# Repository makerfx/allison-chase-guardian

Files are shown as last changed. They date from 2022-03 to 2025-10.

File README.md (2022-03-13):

# Allison Chase's Decayed Guardian Cosplay from Breath of the Wild
This repository holds the code for the interactive bits of Allison Chase's Decayed Guardian Cosplay from Breath of the Wild

Check out Allison's [GOFUNDME for the Guardian Cosplay](https://www.gofundme.com/f/decayed-guardian-cosplay) for more info, follow [Allison on Instagram](https://www.instagram.com/aachase1401) and on [TikTok](https://www.tiktok.com/@allison.chase.cosplay) for build progress!

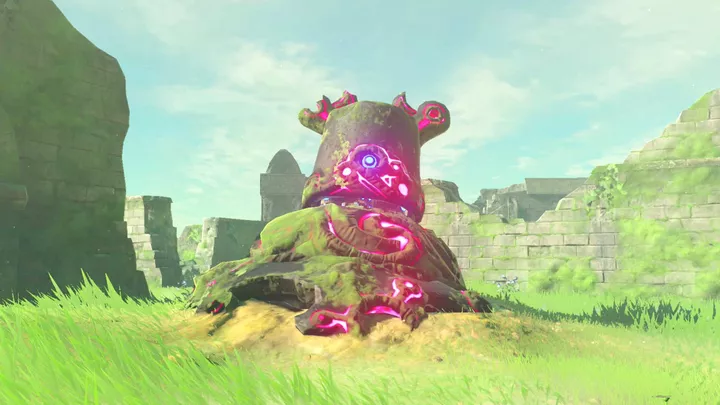
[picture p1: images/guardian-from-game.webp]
Decayed Guardian from Breath of the Wild


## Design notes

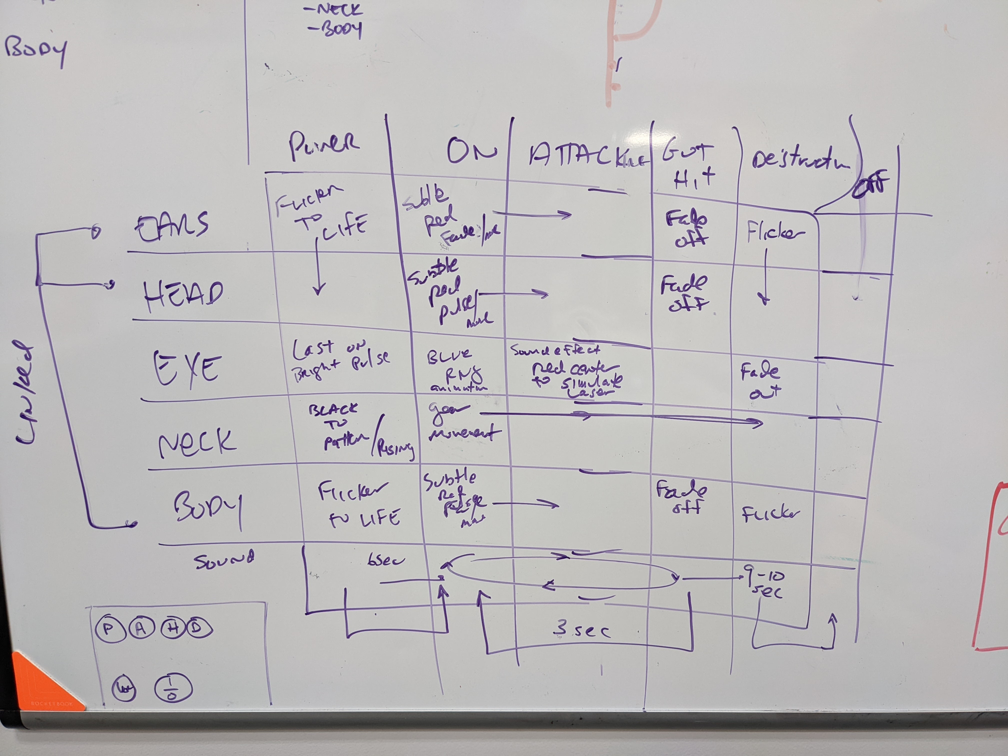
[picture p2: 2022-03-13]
images/modes-whiteboard.jpeg

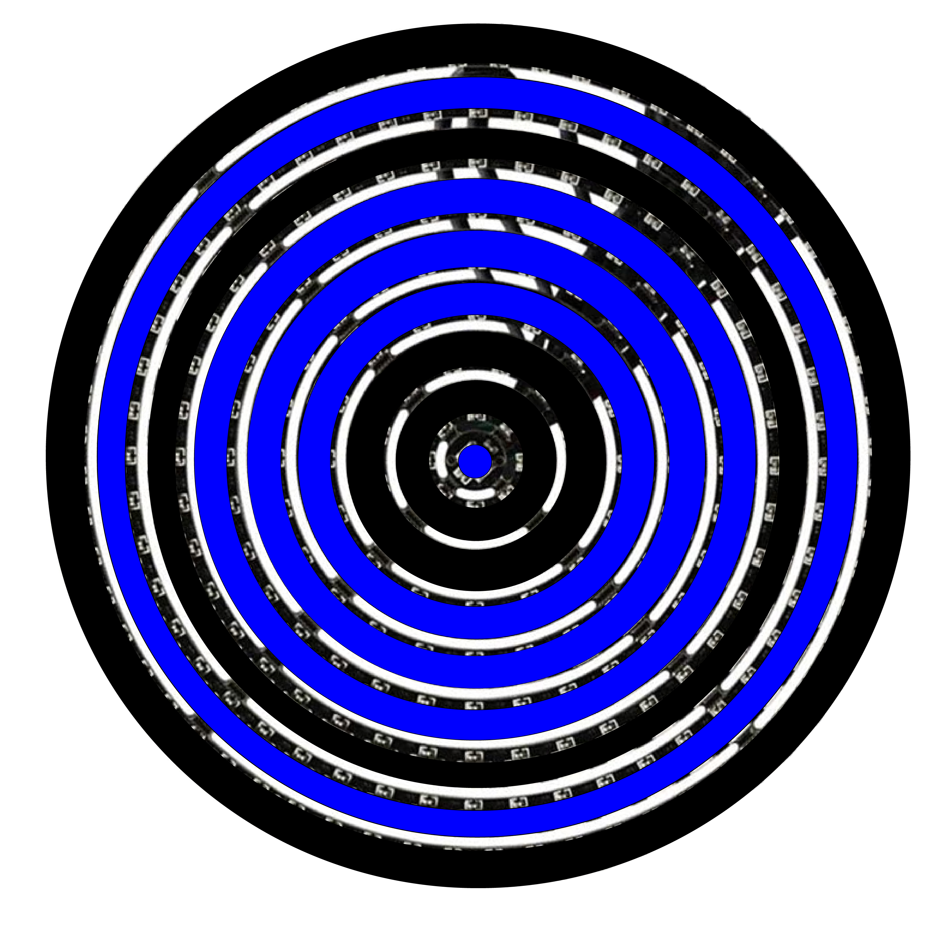
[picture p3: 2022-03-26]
images/pixel-ring-mockups/pixel-ring-mockup-02.png

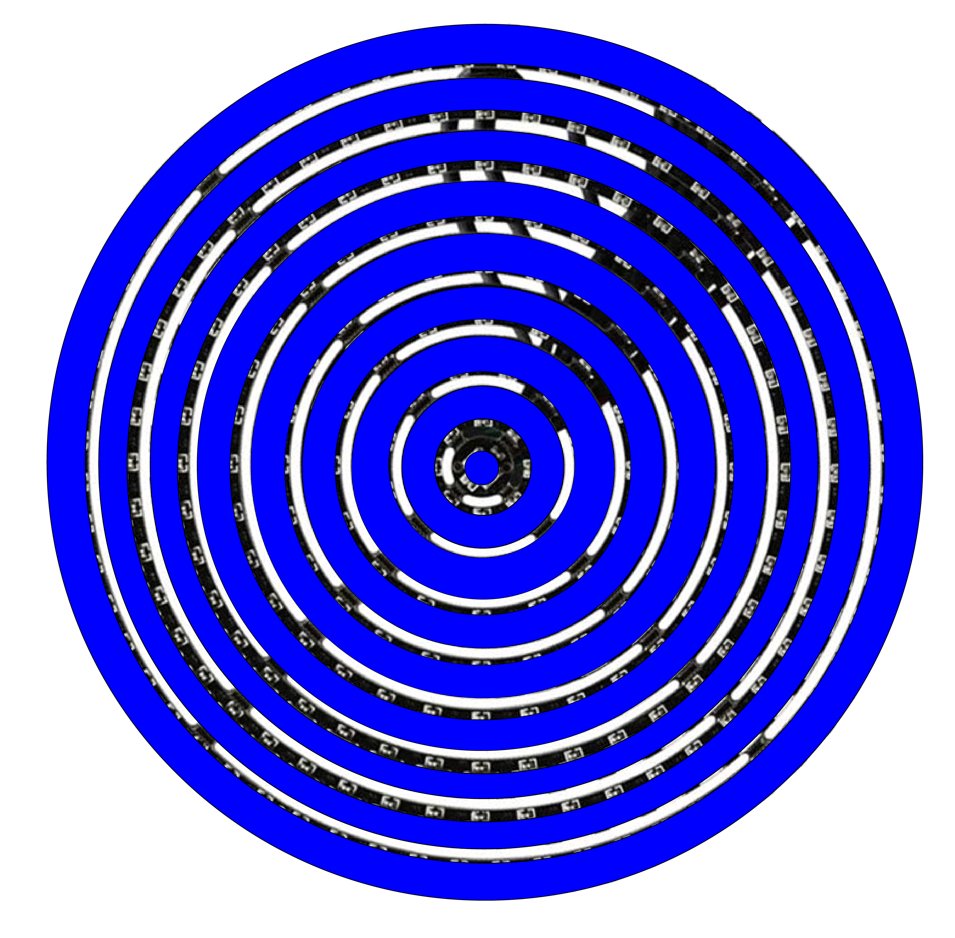
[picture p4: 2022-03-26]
images/pixel-ring-mockups/pixel-ring-mockup-01.png

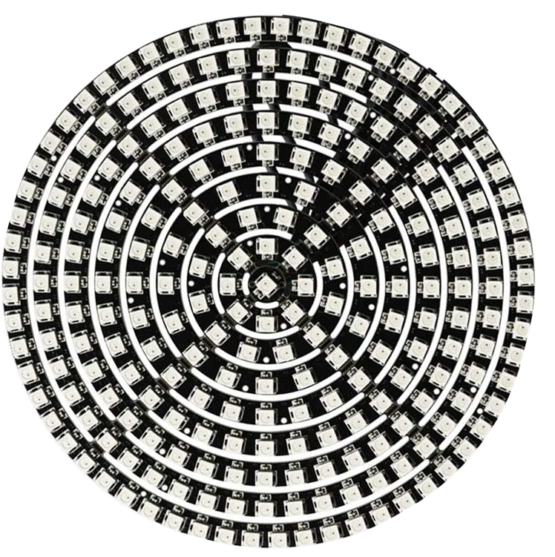
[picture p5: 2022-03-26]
images/pixel-ring.png

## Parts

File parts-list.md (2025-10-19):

# Allison Chase Decayed Guardian Parts List

## Controller & Interface
- Magic Wheelchair "Motherboard" v1.0.7 from MakerFX / 2-Pi Labs
  - 12v -> 5v LM2596 Power Regulator ($1.25) [Amazon Link](https://www.amazon.com/gp/product/B07RLR8PBF)
  - Teensy 4.1 ($26.85): [PJRC link - Buy direct!](https://www.pjrc.com/store/teensy41.html) (also available on amazon)
  - Teensy Audio board REV D for Teensy 4 ($13.75): [PJRC link - Buy direct!](https://www.pjrc.com/store/teensy3_audio.html)
  - Header pins for protoboards ($13 kit): https://smile.amazon.com/gp/product/B07CWSXY7P/
  - 8GB Micro SD Card - SanDisk Industrial with reader ($13.43) [Amazon Link](https://www.amazon.com/gp/product/B085GL8XBH)
  - USB Host Cable for Teensy ($8 for 2): https://www.amazon.com/gp/product/B06Y5M6JTV
  - 5 Key OSU Keyboard ($24.99): [Amazon Link](https://www.amazon.com/gp/product/B08R9GN82G/?th=1)
  - Wireless Presenter Remote ($14.59): [Amazon Link](https://www.amazon.com/gp/product/B01410YNAM/) (STILL NOT INTEGRATED)
  - OLED screen .91 inch ($12.99): [Amazon Link](https://www.amazon.com/gp/product/B07PDFCVXL)

## Power
- Batteries - GigaParts PO4Power 12V 24AH LifePO4 Battery x4 (two on-board, two reserve) ($199.99 each)
- Battery Mount - 3D Printed from DeltaMaker - STL file in Repo
- Battery Straps ($6.99) - [Amazon Link](https://www.amazon.com/gp/product/B078P3GMWV)
- Battery Charger (Loaner from MakerFX - $105.00) - [Amazon Link](https://www.amazon.com/gp/product/B08C2JN76Q)
- Power Supply 12v 600watt Max ($59.99) - [Amazon Link](https://www.amazon.com/gp/product/B082NSVWJY)
- Power Regulation 12v -> 5v @ 20amp x2 ($17.99 each) [Amazon Link](https://smile.amazon.com/gp/product/B089M5R3NJ)
- Fuse Block - 6 circuit with ground bus x2 (18.89 each) [Amazon Link](https://www.amazon.com/gp/product/B08NPMFBBW/)
- XT90 Battery Connectors - 3 pairs - 2x ($13.99 each) [Amazon Link](https://www.amazon.com/gp/product/B08L3RS5HP)
- Main Battery Cable - 10 gauge stranded speaker wire 100 ft ($39.95) [Amazon Link](https://www.amazon.com/gp/product/B00J357DGW)
- Power Distribution Cable - 16 gauge 2 conductor 100 ft. ($18.99) [Amazon Link](https://www.amazon.com/gp/product/B07SG23DT1)

## Cable Management
- Ceiling Cable Management System for VR ($20.79) [Amazon Link](https://www.amazon.com/gp/product/B0777H24ZG)

## LEDs (>3500!)
- Eye + Body Circles: 241 LED Concentric Rings($29) [Amazon Link](https://smile.amazon.com/gp/product/B083VWVP3J)= 177 LEDs (we did not use the outer ring)
- Ears: WS2812 5.5mm Narrow White PCB 2m 120 LEDs ($18.49 each) [Amazon link](https://smile.amazon.com/gp/product/B08SBWCVGX) x6 = 720 LEDs
- Body: WS2812 White PCB 5m 300 LEDs ($33.49 each) [Amazon Link](https://smile.amazon.com/gp/product/B01CDTEH3Q/) x6 = 1800 LEDs
- Neck: WS2812 Black PCB 5m 300 LEDs ($33.49 each) [Amazon Link](https://smile.amazon.com/gp/product/B01CDTEKAG) x3 = 900 LEDs
- Male/Female LED connector ($10.99) [Amazon Link](https://smile.amazon.com/dp/B00NBSH4CA/)
- LED Extension Cable: 3 pin 18 gauge 10m () x2 ($12.49 each) [Amazon Link](https://www.amazon.com/gp/product/B07SKGTCWQ)
- LED Data cable 18 gauge green 100ft ($13.22) [Amazon Link](https://www.amazon.com/gp/product/B00J31QVDC)

## Camera System
- Automotive Dashcam System ($105.00) [Amazon Link](https://www.amazon.com/gp/product/B0824M6YKF)
- Sandisk 128GB MicroSD card ($17.99) [Amazon Link](https://www.amazon.com/gp/product/B08GYKNCCP)

## Audio
 - Amplified Speakers ($99.99) [Best Buy Link](https://www.bestbuy.com/site/boss-audio-systems-mcbc425ba-black-chrome/)
 - PAC Noise Filter ($11.49) [Amazon Link](https://www.amazon.com/gp/product/B01LXGH3KC/ref)
 - Headphone Extension Cable 15 feet [Amazon Link](https://www.amazon.com/gp/product/B091KK5HGG)

## Cooling Fan
 - 12v fan pulled from an old computer power supply at MakerFX

## Other Misc Supplies
- 16mm Thread Male Female Panel Metal Aviation Connector Plug - 2x 4pin & 2x 5pin  ($19.93 for assortment) [Amazon Link](https://www.amazon.com/gp/product/B07F5B5LLX)
- LOTS of crimp on rings from Skycraft Surplus

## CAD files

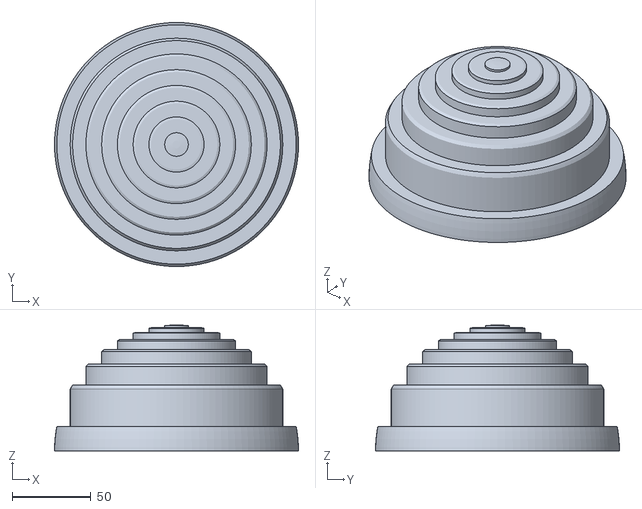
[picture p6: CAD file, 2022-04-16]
3D-printing/led2_2_70mm.stl
154.9 x 154.9 x 80.0

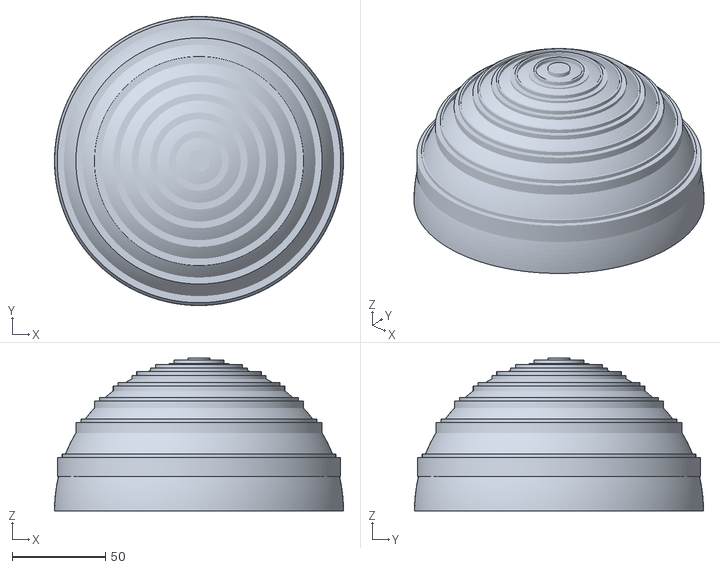
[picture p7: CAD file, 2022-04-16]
3D-printing/ac-guardian-dome-v2-defaults.stl
155.0 x 155.0 x 82.0

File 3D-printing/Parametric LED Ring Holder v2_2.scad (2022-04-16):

/////IGNORE, SETTING VARIABLES/////

/* [Hidden] */
//Resolution 
$fn = 100;
ring1 = 12;
ring2 = 32;
ring3 = 52;
ring4 = 72;
ring5 = 92;
ring6 = 112;
ring7 = 132;
ring8 = 152;
ring9 = 172;

//Width of platform (in mm)
ringBaseWidth = 8.2;

ringBaseHeight = 1;

///////////////////////////////////////////////////////////////





/////EDIT INFO BELOW FOR CUSTOMIZATION/////
/* [Parameters] */
//Overall height of model (in mm)
domeHeight = 80;
//Overall width of model (in mm)
domeWidth = 155;
//Thickness of dome shell (in mm)
domeThickness = 10;

includeRing1 = true;
includeRing2 = true;
includeRing3 = true;
includeRing4 = true;
includeRing5 = true;
includeRing6 = true;
includeRing7 = true;
includeRing8 = true;
includeRing9 = false;





/////////////////////////////////////////////////////////////
////Setup////

// Creating ringsActive vector
ringsAvailable = [ring1, ring2, ring3, ring4, ring5, ring6, ring7, ring8, ring9];

includes = [includeRing1, includeRing2, includeRing3, includeRing4, includeRing5, includeRing6, includeRing7, includeRing8, includeRing9];

ringsActive = [
    for(i = [0:len(ringsAvailable) - 1])
    if(includes[i])
    ringsAvailable[i]
];
    
ringNumber = len(ringsActive);

assert(ringsActive[ringNumber-1]<=domeWidth, "One or more of the rings selected will not fit within the dome");
    

difference(){
union(){
    difference(){
color("red")
    scale([1, 1, (domeHeight*2)/domeWidth]) sphere(d = domeWidth);
    for(i=[0:ringNumber-1])
{
  translate([0,0,(domeHeight*sqrt(pow((domeWidth/2),2)-pow((ringsActive[i]/2),2))/(domeWidth/2))])
    scale([1,1,domeHeight]) difference(){
      cylinder(h=ringBaseHeight, d=ringsActive[i], center=false);
      cylinder(h=ringBaseHeight+2, d=ringsActive[i]-((ringBaseWidth*2)+.6), center=false);
    }
}
  }
    
color("cyan")
  if (ringsActive[0] == ring1)
  {
    union(){
    translate([0,0,(domeHeight*sqrt(pow((domeWidth/2),2)-pow((6),2))/(domeWidth/2))]) cylinder(h=.1, d=14.5, center=false);
    difference(){
        translate([0,0,(domeHeight*sqrt(pow((domeWidth/2),2)-pow((6),2))/(domeWidth/2))]) cylinder (h=2, d=14.5, center=false);
        translate([0,0,(domeHeight*sqrt(pow((domeWidth/2),2)-pow((6),2))/(domeWidth/2))]) cylinder (h=2.2, d=12.5, center=false);
          }
      }
  }
}
color("red")
scale([1, 1, (domeHeight*2)/domeWidth]) sphere(d = domeWidth-(domeThickness*2));
translate([0,0,-domeHeight]) cube([domeWidth,domeWidth,domeHeight*2],center = true);
}

        

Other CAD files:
3D-printing/Parametric LED Ring Holder v2.scad
3D-printing/Parametric LED Ring Holder v2_1.scad

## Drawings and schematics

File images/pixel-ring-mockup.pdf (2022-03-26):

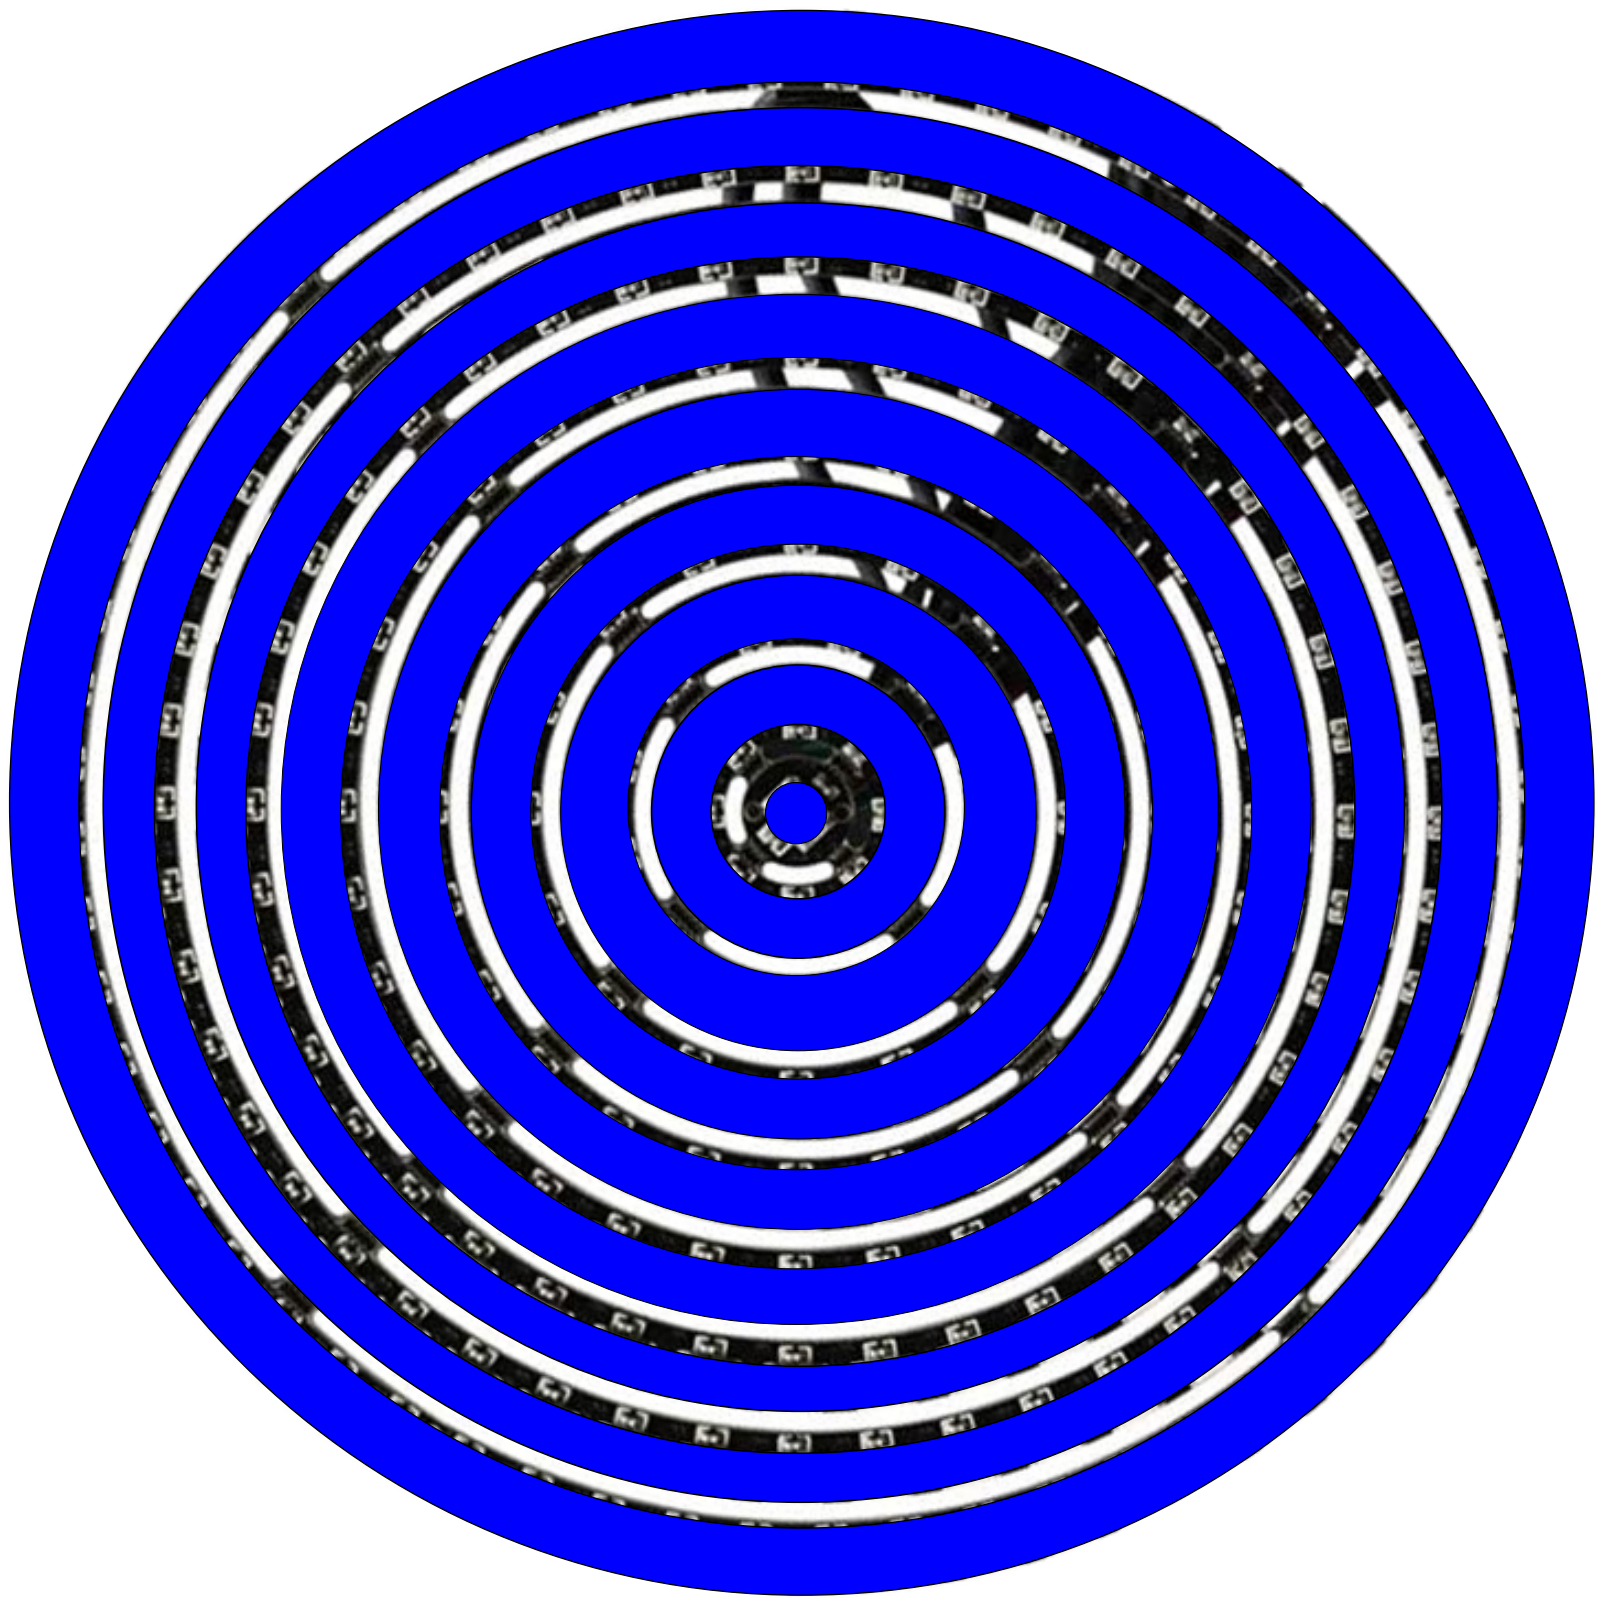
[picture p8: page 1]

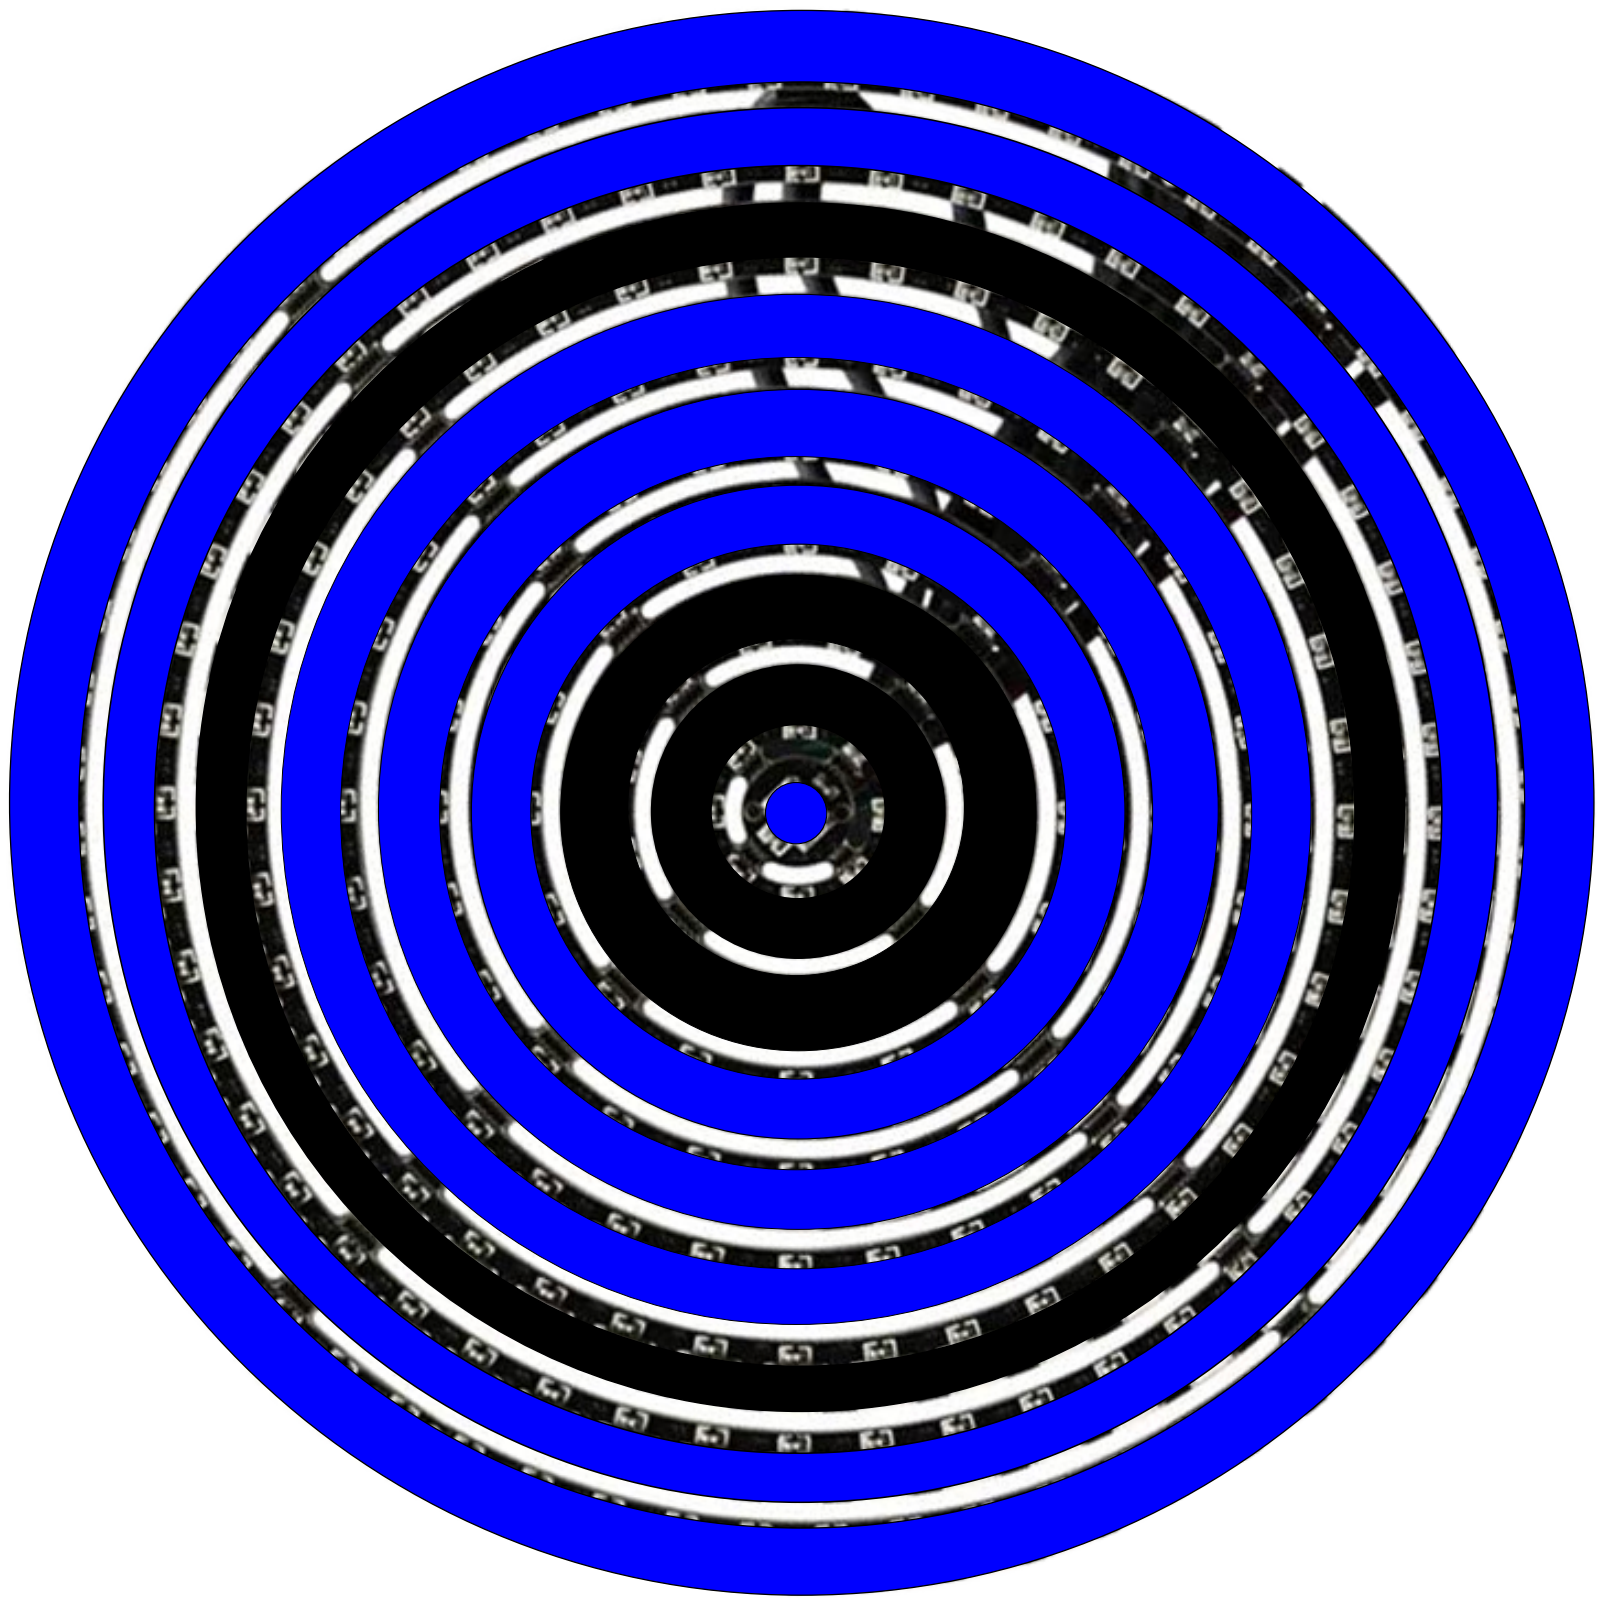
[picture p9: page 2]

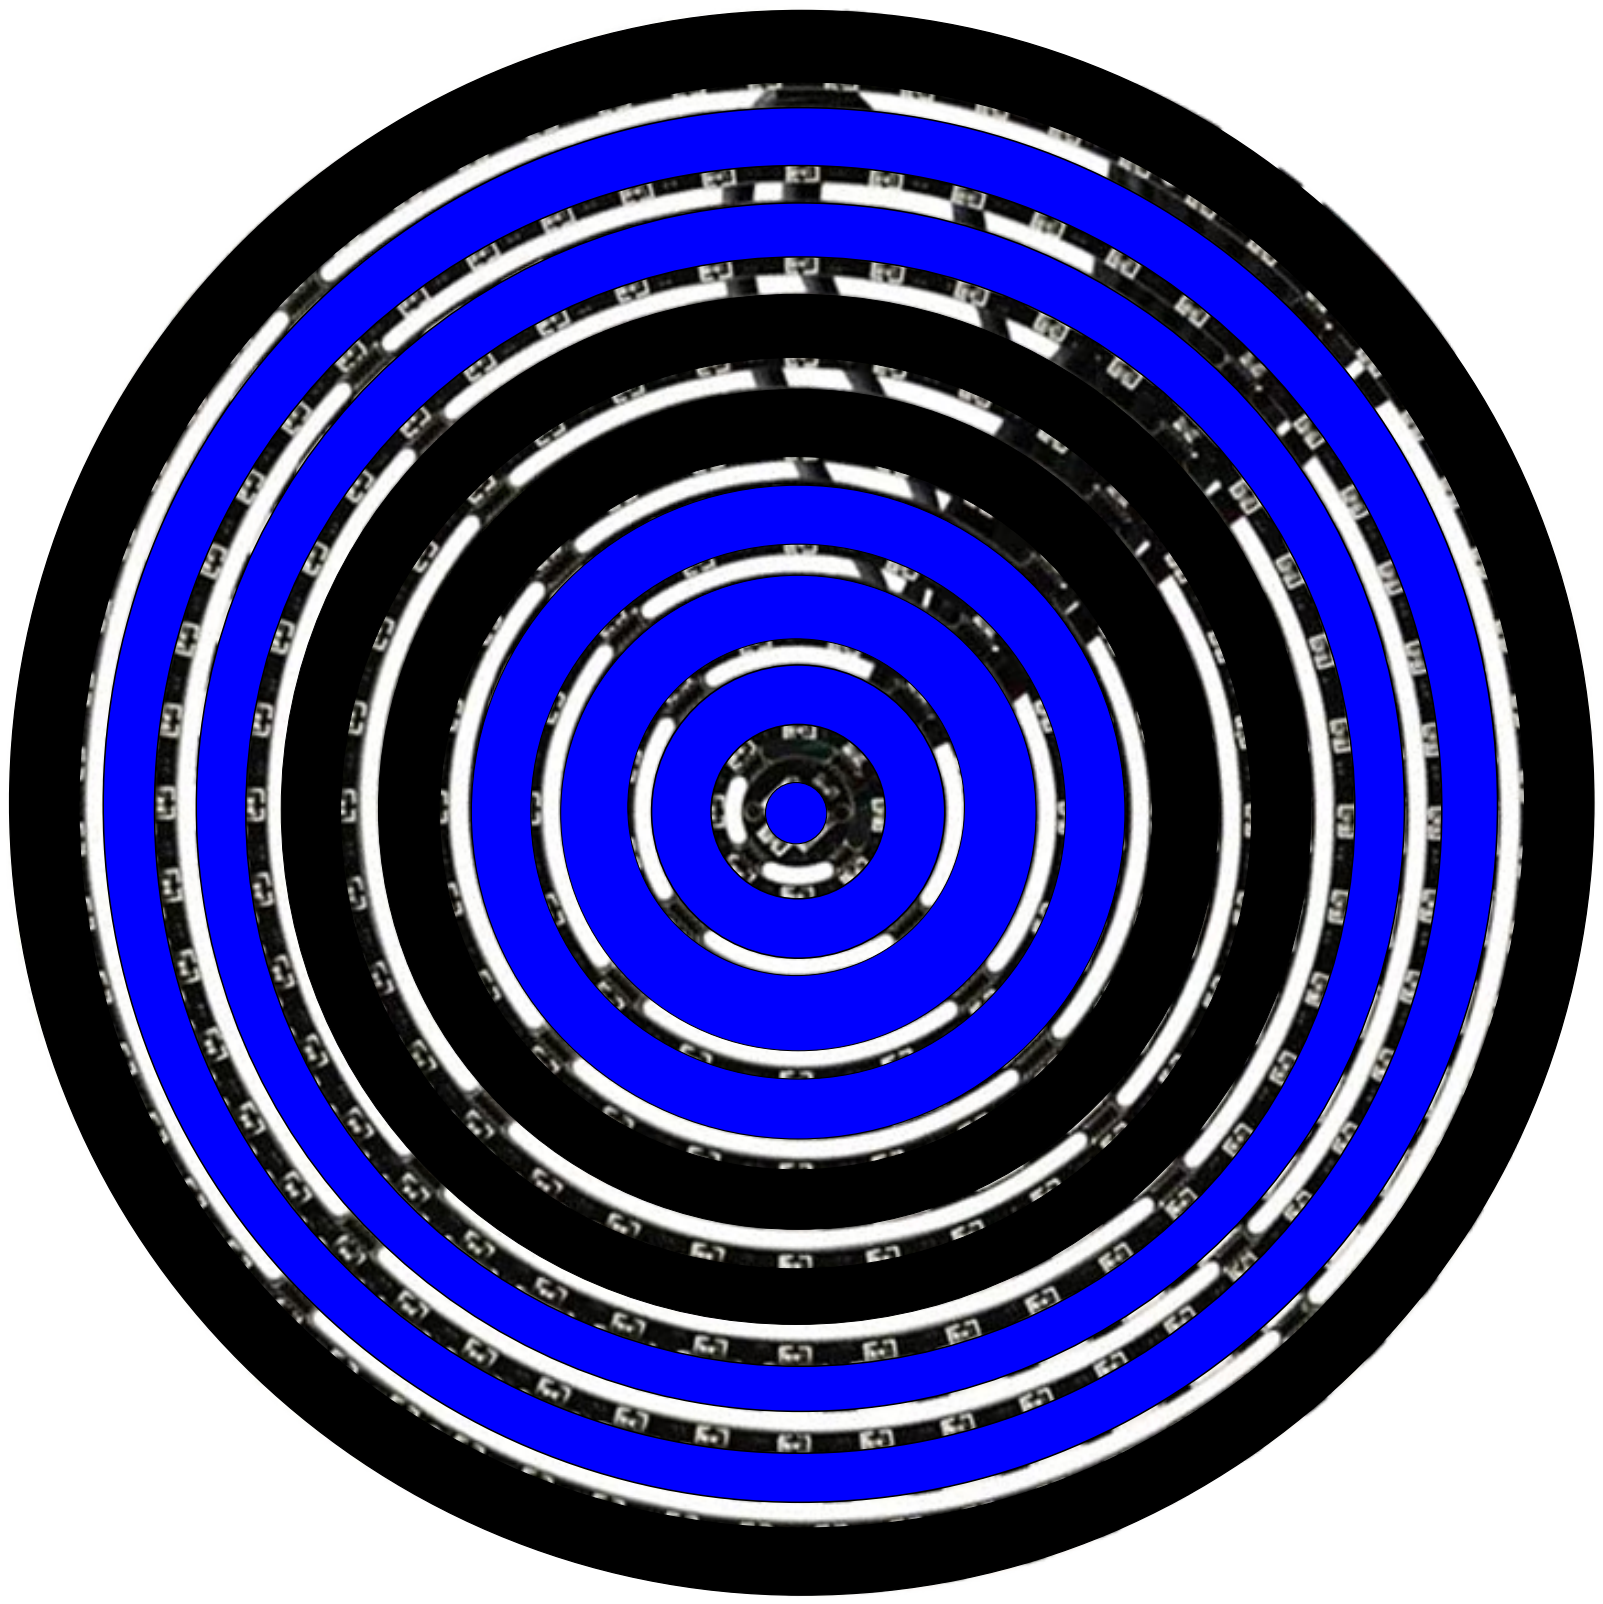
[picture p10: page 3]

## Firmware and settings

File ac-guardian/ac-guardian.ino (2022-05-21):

#include "ac-guardian.h"

void setup() {
  // put your setup code here, to run once:
  randomSeed(analogRead(0));
  Serial.begin(115200);
  delay(200);

  //usb setup
  //don't forget to add these for EVERY keyboard :)
  
  osukey1.attachRawPress(OnPress);
  osukey1.attachRawRelease(OnRelease);
  osukey2.attachRawPress(OnPress);
  osukey2.attachRawRelease(OnRelease);
  osukey3.attachRawRelease(OnRelease);
  osukey3.attachRawPress(OnPress);
  osukey4.attachRawRelease(OnRelease);
  osukey4.attachRawPress(OnPress);
  osukey5.attachRawRelease(OnRelease);
  osukey5.attachRawPress(OnPress);
  myusb.begin();
  
  //display init
  // SSD1306_SWITCHCAPVCC = generate display voltage from 3.3V internally
  if(!display.begin(SSD1306_SWITCHCAPVCC, 0x3C)) { // Address 0x3C for 128x32
    Serial.println(F("SSD1306 allocation failed"));
    for(;;); // Don't proceed, loop forever
  }
  Serial.println("OLED begun");
  
  // Clear the buffer
  display.clearDisplay();

  // text display tests
  display.setTextSize(1);
  display.setTextColor(SSD1306_WHITE);
  display.setCursor(0,0);
  display.println(__FILENAME__);
  display.print(__DATE__);
  display.print(" ");
  display.println(__TIME__);
  display.println("Initializing...");
  display.display(); // actually display all of the above

  Serial.println("Setup Started.");

    //setup audio system
  AudioMemory(128);
  sgtl5000_1.enable();
  sgtl5000_1.volume(mainVolume);

  //set relative volumes by channel
  mixer1.gain(0, LEVEL_CHANNEL0);
  mixer2.gain(0, LEVEL_CHANNEL0);
  mixer1.gain(1, LEVEL_CHANNEL1);
  mixer2.gain(1, LEVEL_CHANNEL1);
  mixer1.gain(2, LEVEL_CHANNEL2);
  mixer2.gain(2, LEVEL_CHANNEL2);

  //setup SD card
  SPI.setMOSI(SDCARD_MOSI_PIN);
  SPI.setSCK(SDCARD_SCK_PIN);
  if (!(SD.begin(SDCARD_CS_PIN))) {
    while (1) {
      Serial.println("Unable to access the SD card");
      delay(500);
    }
  }
  
  LEDS.addLeds<WS2812SERIAL,  NECK_DATA_PIN,   BRG>(neckLEDs,  NUM_NECK_LEDS);
  LEDS.addLeds<WS2812SERIAL,  EYE_DATA_PIN,    BRG>(eyeLEDs,   NUM_EYE_LEDS);
  LEDS.addLeds<WS2812SERIAL,  BODY_DATA_PIN,   BRG>(bodyLEDs,  NUM_BODY_LEDS);
  
    
  //LEDS.setBrightness(DEFAULT_BRIGHTNESS);
  updateBrightness(); //will set the default
  
  //build the top ring pattern to be copied later
  for (int i=0; i<NECK_TOP_GEARS_NUM; i++) { 
     for (int j=0; j<NECK_TOP_GEAR_WIDTH; j++) {
        if (j==0 || j==3) neckTopPattern[i*NECK_TOP_GEAR_WIDTH + j] = 1;
        else neckTopPattern[i*NECK_TOP_GEAR_WIDTH + j] = 0;
      }
  }

  if (debugOptions[DEBUG_ANIMATION_NECK]) {
    //print the ring pattern
    for (int i=0; i<NUM_NECK_LEDS_PER_RING ; i++) { 
       Serial.print(neckTopPattern[i]);
    }   
    Serial.println("");  
  }

  //build the body pattern
  generateBodyPattern();


  delay (2000);
  display.clearDisplay();
  display.setCursor(0,0);
  display.println("Running...");
  display.setCursor(0,0);
  display.display(); // actually display all of the above
  printDebugOptions();

/*
  Serial.println(bodySpotColor.red);
  Serial.println(bodySpotColor.green);
  Serial.println(bodySpotColor.blue);

  Serial.println("");
  Serial.println(bodySpotGapColor.red);
  Serial.println(bodySpotGapColor.green);
  Serial.println(bodySpotGapColor.blue);
 */
  
  //modePowerUp();
}

void loop() {

  EVERY_N_MILLISECONDS(10) {                           
    FastLED.show();
    gHue++; 
  }
  
  EVERY_N_MILLISECONDS(100) {                           
    updateOLED();
    //FastLED.show();
    debugOptionsCheck();
  }
   
   if (queueMetro.check() == 1) { //time to process the queues

    for (int q = 0; q < NUM_ACTIONS; q++) {
      unsigned long qTime = actionQueue[q];
      if (qTime && (millis() > qTime)) {
        if (debugOptions[DEBUG_ACTION]) Serial.printf ("Action Called: %s \n", actionsText[q]);
        if (q==ACTION_FADE_OUT_EYE) eyeAniMode = 0;
        else if (q==ACTION_FADE_IN_EYE) eyeAniMode = 1;       
        else if (q==ACTION_FADE_OUT_NECK) neckAniMode = 0;
        else if (q==ACTION_FADE_IN_NECK) neckAniMode = 1;
        else if (q==ACTION_FADE_OUT_BODY) bodyAniMode = 0;
        else if (q==ACTION_FADE_IN_BODY) bodyAniMode = 1;
        else if (q==ACTION_PLAY_LASER_SOUND) playWAV(CHANNEL_SFX1, "ACGLAZR1.WAV"); //todo: something with the body lights?
        
        else if (q==ACTION_SET_MODE_OFF) mode = MODE_OFF;
        else if (q==ACTION_SET_MODE_IDLE) mode = MODE_IDLE;
        
        actionQueue[q]=0;
      }
    }
    
  

    bool block = false;
    //play any queued music
    for (int q = 0; q < NUM_CHANNELS; q++) {
      String fn = playQueue[q];
      if (fn.length() >0) {
        playQueue[q] = "";
        playWAV(q,fn); 
        block = true;
      }
    }

    //loop BGM if needed - todo: have global for filename to loop
    if ( !block && (musicLoop==true) && !(channels[CHANNEL_MUSIC]->isPlaying())) {
      if(debugOptions[DEBUG_AUDIO]) Serial.println("Audio: restarting music loop");
      //playWAV(CHANNEL_MUSIC, "ACGBATL2.WAV");
      playWAV(CHANNEL_MUSIC, musicLoopFilename);
      if (mode == MODE_POWER_UP) mode = MODE_IDLE;
    }
  } //end playQueueMetro check
  
  if (brMetro.check() == 1) { // check if the bottom ring metro has passed its interval 
    if (neckAniMode == 0) fadeToBlackBy(neckLEDs+NUM_NECK_LEDS_PER_RING, NUM_NECK_LEDS_PER_RING*(NUM_NECK_RINGS-1), 60);
    else if (neckAniMode == 1) updateNeckBottomRings();
    
  }

  if (trMetro.check() == 1) { // check if the top ring metro has passed its interval 
     if (neckAniMode == 0) fadeToBlackBy(neckLEDs, NUM_NECK_LEDS_PER_RING, 60); //just the top ring
     else if (neckAniMode == 1) updateNeckTopRing();
   
 
  } //end trMetro 
   
  if (eyeMetro.check() == 1) { // check if the eye metro has passed its interval 
  
   if (eyeAniMode == 0) fadeToBlackBy(eyeLEDs, NUM_EYE_LEDS, 60);
   else if (eyeAniMode == 1) updateEyeRingStatus();
   else if (eyeAniMode == 2) updateEyeTargeting();
   
  }  //end eyeMetro 
  
  if (bodyMetro.check() == 1) updateBodyLEDs();
  
}

/*
 * generateBodyPattern() - this function generates a random pattern that is then animated
 *                        by updateBodyLEDs()
 *                        
 */
void generateBodyPattern() {
  bool pType = 1;
  CRGB pVal;
  uint8_t pLen;
  
  for (uint16_t l=0; l<NUM_BODY_LEDS; l++) {
    if (pType) {
      pLen = random(BODY_SPOT_LEN_MIN, BODY_SPOT_LEN_MAX);
      //pVal = BODY_SPOT_V;
      //pVal = BODY_SPOT_COLOR;
      pVal = bodySpotColor;

      }
    else {
      pLen = random(BODY_SPOT_GAP_LEN_MIN, BODY_SPOT_GAP_LEN_MAX);
      //pVal = BODY_BASE_V;
      //pVal = BODY_SPOT_GAP_COLOR;
      pVal = bodySpotGapColor;
    }

    for (uint8_t pLED = 0; pLED<pLen; pLED++) {
      //Serial.print(l+pLED);
      
      if (l+pLED>=NUM_BODY_LEDS) break;
      bodyPattern[l+pLED] = pVal;
 
      /*
       if (pVal == bodySpotColor) {
        Serial.print("#");
      }
      else if (pVal == bodySpotGapColor) Serial.print(".");
      */
    }
 
    l = l + pLen - 1;
    if (l>=NUM_BODY_LEDS) break;
    pType = !pType;
  }
}

void updateBodyLEDs() {
  if (bodyAniMode == 0) {
    fadeToBlackBy(bodyLEDs, NUM_BODY_LEDS, 60);
    return;
  }
  else if (bodyAniMode == 1) {//normal body operation

    if (bodyOffset == bodyTarget) {
          bodyDir = !bodyDir;
          bodyTarget = random(0, NUM_BODY_LEDS);
          if (random(1,20) >= BODY_SPEED_RANDOM_CHECK_TURN) {
              bodySpeed = random(BODY_SPEED_MIN,BODY_SPEED_MAX);
          }
          bodyMetro.interval(bodySpeed);
          //Serial.print("reverse - new target = "); Serial.println(bodyTarget);
        }
      
        //decel math
        int dist = abs(bodyOffset-bodyTarget);
        
        if (dist < BODY_DECEL_DISTANCE) {
          int temp_bodySpeed = bodySpeed * (BODY_DECEL_FACTOR/dist);
          if (temp_bodySpeed > BODY_SPEED_MAX_DECEL) {
            temp_bodySpeed = BODY_SPEED_MAX_DECEL;
            bodyMetro.interval(temp_bodySpeed);
          }
          else {
            //random speed changes
            if (random(1,20) >= BODY_SPEED_RANDOM_CHECK) {
              bodySpeed = random(BODY_SPEED_MIN,BODY_SPEED_MAX);
            }
            bodyMetro.interval(bodySpeed);
          }
        }
        
        if (bodyDir) bodyOffset++;
        else bodyOffset --;
      
        
       
        if (bodyOffset >= NUM_BODY_LEDS ) bodyOffset = 0;
        if (bodyOffset < 0) bodyOffset = NUM_BODY_LEDS-1;
        
        //Serial.println(""); Serial.print(bodyOffset); Serial.print("->");
        
        //copy the pattern onto the LED array starting from the top ring offset
        for (int i=0; i<NUM_BODY_LEDS ; i++) { 
           int lo = NUM_BODY_LEDS - bodyOffset + i;
           if (lo > NUM_BODY_LEDS - 1) lo= lo-NUM_BODY_LEDS ;
            bodyLEDs[i] = bodyPattern[lo];
        }  

    }
    else if (bodyAniMode == 2) {//rainbow!!
      //rainbowHue=rainbowHue+10;
      fill_rainbow( bodyLEDs, NUM_BODY_LEDS, gHue, 7);
    }
/*
  //copy the pattern to the LEDs
  for (uint16_t l=0; l<NUM_BODY_LEDS; l++) {
    bodyLEDs[l] = CRGB::Red; 
    bodyLEDs[l] = CHSV(BODY_HUE, 255, bodyPattern[l]);
  }
 */  
 
}
void updateNeckTopRing() {
  
    if (topRingOffset == topRingTarget) {
      topRingDir = !topRingDir;
      topRingTarget = random(0, NUM_NECK_LEDS_PER_RING);
      if (random(1,20) >= TOP_RING_SPEED_RANDOM_CHECK_TURN) {
          topRingSpeed = random(TOP_RING_SPEED_MIN,TOP_RING_SPEED_MAX);
      }
      trMetro.interval(topRingSpeed);
      //Serial.print("reverse - new target = "); Serial.println(topRingTarget);
    }
  
    //decel math
    int dist = abs(topRingOffset-topRingTarget);
    
    if (dist < TOP_RING_DECEL_DISTANCE) {
      int temp_topRingSpeed = topRingSpeed * (TOP_RING_DECEL_FACTOR/dist);
      if (temp_topRingSpeed > TOP_RING_SPEED_MAX_DECEL) {
        temp_topRingSpeed = TOP_RING_SPEED_MAX_DECEL;
        trMetro.interval(temp_topRingSpeed);
      }
      else {
        //random speed changes
        if (random(1,20) >= TOP_RING_SPEED_RANDOM_CHECK) {
          topRingSpeed = random(TOP_RING_SPEED_MIN,TOP_RING_SPEED_MAX);
        }
        trMetro.interval(topRingSpeed);
      }
    }
    
    if (topRingDir) topRingOffset++;
    else topRingOffset --;
  
    
   
    if (topRingOffset >= NUM_NECK_LEDS_PER_RING ) topRingOffset = 0;
    if (topRingOffset < 0) topRingOffset = NUM_NECK_LEDS_PER_RING-1;
    
    //Serial.println(""); Serial.print(topRingOffset); Serial.print("->");
    
    //copy the pattern onto the LED array starting from the top ring offset
    for (int i=0; i<NUM_NECK_LEDS_PER_RING-1 ; i++) { 
       int lo = NUM_NECK_LEDS_PER_RING - topRingOffset + i;
       if (lo > NUM_NECK_LEDS_PER_RING - 1) lo= lo-NUM_NECK_LEDS_PER_RING ;
       if (neckTopPattern[lo]) neckLEDs[i] = CRGB::Blue; 
       else neckLEDs[i] = CRGB::Black;
    }
    //copy the pattern onto the second row of LEDs in reverse (because I had to make things complicated!)
    for (int i=0; i<NUM_NECK_LEDS_PER_RING-1 ; i++) { 
       neckLEDs[i+NUM_NECK_LEDS_PER_RING] = neckLEDs[NUM_NECK_LEDS_PER_RING-i-1];
    }  

    
}
void updateNeckBottomRings() {
  if (bottomRingOffset == 0) bottomRingTargetCycles--;
    if (bottomRingTargetCycles < 0) bottomRingTargetCycles = 0;
  
    if ((bottomRingOffset == bottomRingTarget) && (bottomRingTargetCycles ==0)) {
      bottomRingDir = !bottomRingDir;
      bottomRingTarget = random(0, BOTTOM_RING_GEAR_SIZE);
      bottomRingTargetCycles = random(0, BOTTOM_RING_MAX_CYCLES);
      
      if (random(1,20) >= BOTTOM_RING_SPEED_RANDOM_CHECK_TURN) {
          bottomRingSpeed = random(BOTTOM_RING_SPEED_MIN,BOTTOM_RING_SPEED_MAX);
      }
      brMetro.interval(bottomRingSpeed);
      //Serial.print("reverse - new target = "); Serial.println(bottomRingTarget);
    }
  
    //decel math
    int dist = abs(bottomRingOffset-bottomRingTarget);
    
    if (dist < BOTTOM_RING_DECEL_DISTANCE) {
      int temp_bottomRingSpeed = bottomRingSpeed * (BOTTOM_RING_DECEL_FACTOR/dist);
      if (temp_bottomRingSpeed > BOTTOM_RING_SPEED_MAX_DECEL) {
        temp_bottomRingSpeed = BOTTOM_RING_SPEED_MAX_DECEL;
        brMetro.interval(temp_bottomRingSpeed);
      }
      else {
        //random speed changes
        if (random(1,20) >= BOTTOM_RING_SPEED_RANDOM_CHECK) {
          bottomRingSpeed = random(BOTTOM_RING_SPEED_MIN,BOTTOM_RING_SPEED_MAX);
        }
        brMetro.interval(bottomRingSpeed);
      }
    }
    
    if (bottomRingDir) bottomRingOffset++;
    else bottomRingOffset --;
  
    if (bottomRingOffset >= BOTTOM_RING_GEAR_SIZE ) bottomRingOffset = 0;
    if (bottomRingOffset < 0) bottomRingOffset = BOTTOM_RING_GEAR_SIZE-1;
    
    /*if (debugOptions[DEBUG_ANIMATION_NECK]) {
      Serial.println(""); //Serial.print(bottomRingOffset);Serial.println("->");
    }
  */
    bool tempLEDs[NUM_NECK_RINGS][NUM_NECK_LEDS_PER_RING];

    //init the array with zeros.... NEEDED?
    for (int r = 0; r<NUM_NECK_RINGS; r++) {
      for (int l = 0; l<NUM_NECK_LEDS_PER_RING; l++) {
        tempLEDs[r][l]=0; //clear 
      }
    }
   
    
    for (int r = 0; r<NUM_NECK_RINGS-1; r++) {                                                          //for each ring
      int curLED = 0;
      for (int g = 0; g<(NUM_NECK_LEDS_PER_RING / BOTTOM_RING_GEAR_SIZE)+1 ; g++) {                // for each gear //+1 is hack to fit

        if (g%2==0) { //even number
                                                                    
            for (int l=0; l<BOTTOM_RING_GEAR_SIZE; l++) {
              int lo =  BOTTOM_RING_GEAR_SIZE - bottomRingOffset + l;
              if (lo > BOTTOM_RING_GEAR_SIZE -1) lo= lo- BOTTOM_RING_GEAR_SIZE;
              //Serial.print(lo);Serial.print(" ");
              tempLEDs[r][curLED] = neckFacet[r][lo];         //map facet pattern 
              curLED++;  
            } //end for l
            //Serial.println("");

            
       
       }
       else { //odd number
           int gearEnd = curLED - 1 ; //last LED of prior gear       
   
           for (int l=0; l<BOTTOM_RING_GEAR_SIZE; l++) {                                         
            tempLEDs[r][curLED] = tempLEDs[r][gearEnd - l];
            curLED++;
            } //end for l
        }

        
        //Serial.print(" ");
        } //end for l
    } //end for r 

   /*
  // crazy debug print version
    if (debugOptions[DEBUG_ANIMATION_NECK]) {
      for (int r = 0; r<NUM_NECK_RINGS-2; r++) { //for each ring
  
        Serial.print(r); Serial.print(": ");
        for (int l = 0; l<NUM_NECK_LEDS_PER_RING; l++) {
          if (tempLEDs[r][l] == 1) Serial.print("#");
          else Serial.print(" ");
          //tempLEDs[r][l]=0;                                               //clear is this needed?
        }
        Serial.println("");
      }
    } 
    */


    //copy the bottom neck rings onto the LED array 
    for (int r = 0; r<NUM_NECK_RINGS-2; r++) { //for each ring
      for (int l = 0; l<NUM_NECK_LEDS_PER_RING; l++) {
          //int ln = (r+1)*NUM_NECK_LEDS_PER_RING+l;
          int ln = 0;
          
          if (r==1 || r ==3) {
              ln = (r+2)*NUM_NECK_LEDS_PER_RING+l; //hack!
          }
          else 
              ln = (r+2+1)*NUM_NECK_LEDS_PER_RING-l-1;
              
          //Serial.print(ln);
          if (tempLEDs[r][l] == 1) {
            neckLEDs[ln] = CRGB::Blue; 
            //Serial.println("*");
          }
          else //Serial.println(""); 
            neckLEDs[ln] = CRGB::Black;                                          
        }  
    }
}

void updateEyeTargeting() {

  eyeMetro.interval(EYE_SPEED_TARGETING);
  
  uint8_t lastLED = -1;
  
  for (int r=0; r<NUM_RINGS; r++) {
    //Serial.print(r);

    uint8_t firstLED = 0;
    
    firstLED = lastLED + 1;
    lastLED =  lastLED + eyeRingLEDSize[r];

    for (int l=firstLED; l<=lastLED; l++){
      if (eyeTargetAniFrames[eyeTargetAniFrame][r]) 
         eyeLEDs[l] = CRGB::Red;
      else eyeLEDs[l] = CRGB::Black; 
    }
    
    if (eyeTargetAniFrame == EYE_TARGET_ANI_FRAMES) {
      fadeToBlackBy(eyeLEDs, NUM_EYE_LEDS, 80);
      eyeAniMode = 1;
      eyeTargetAniFrame = 0;
      if (mode == MODE_ATTACK) mode = MODE_IDLE;
      eyeMetro.interval(EYE_SPEED);
    } //end if
  } //end for

  if (eyeAniMode == 2) eyeTargetAniFrame++;
}

void updateEyeRingStatus() {

  eyeMetro.interval(EYE_SPEED);
  //increment the status array
  boolean eyeRingStatusTemp[EYE_PATTERN_LEN];
     
  for (int i = 0; i<EYE_PATTERN_LEN; i++) {
    eyeRingStatusTemp[i] = eyeRingStatus[i];
  }
  
  for (int i = 0; i<EYE_PATTERN_LEN; i++) {
    if (i==EYE_PATTERN_LEN-1) {
      eyeRingStatus[i] = eyeRingStatusTemp[0];
    }
    else eyeRingStatus[i] = eyeRingStatusTemp[i+1];
  }
  
  
  //update the rings

  uint8_t lastLED = -1;
  
  for (int r = 0; r<NUM_RINGS; r++){
    uint8_t firstLED = 0;
    
    firstLED = lastLED + 1;
    lastLED =  lastLED + eyeRingLEDSize[r];

    for (int l=firstLED; l<=lastLED; l++){
      if (eyeRingStatus[r]) 
         //dim the first and last ring 
         if (r ==0 || r == NUM_RINGS-1) eyeLEDs[l].setHSV(160,255,128); 
         else eyeLEDs[l].setHSV(160,255,255); 
        //eyeLEDs[l] = CRGB::Blue;
      else eyeLEDs[l] = CRGB::Black;

    }     
  }
}

/*
 * debugOptionsCheck() - this function checks the Serial input and
 *                       changes debug options as well as emulates some 
 *                       button presses
 *                       
 */
void debugOptionsCheck() {
  int incomingByte = 0;
  
  if (Serial.available() > 0) {
      // read the incoming byte:
      incomingByte = Serial.read();
      int option;
      
      switch (incomingByte) {
          
          case '0':                         //turn all options off
            for (int o = 1; o<10; o++) {    //we dont use zero
              debugOptions[o] = 0;
            }
            Serial.println ("All debug options turned OFF");
            break;
            
          case '1' ... '9': 
            option = incomingByte - '0';
            debugOptions[option] = !debugOptions[option]; 
            //Serial.printf("Debug option %d is now %s\n", option, debugOptions[option]?"ON":"OFF");
            printDebugOptions();
            break;
   
          case 'q': modePowerUp(); break;
          case 'w': modeAttack(); break;
          case 'e': modeDamaged(); break;
          case 'r': modeDestroyed(); break;
          case 't': volumeUp(); break;
          case 'y': volumeDown(); break;
          case 'c': modeTheChain(); break;
          case 'd': modeVader(); break;
          case 'l': modeLowRider(); break;
          case 'h': modeDrWho(); break;
          
          
          case '<': brightnessDown(); break;
          case '>': brightnessUp(); break;
         // case ',': bodySpotColor+= CRGB(0,10,10); printDebugColor("Body Spot",bodySpotColor); generateBodyPattern(); break;
         // case '.': bodySpotColor-= CRGB(0,10,10); printDebugColor("Body Spot",bodySpotColor); generateBodyPattern(); break;
         // case '<': bodySpotGapColor-= CRGB(10,0,0); printDebugColor("Body Gap",bodySpotGapColor); generateBodyPattern(); break;
         // case '>': bodySpotGapColor+= CRGB(10,0,0); printDebugColor("Body Gap",bodySpotGapColor); generateBodyPattern(); break;
          
          
          }
         
     
          
      }
       
}

void printDebugColor(String colorName, CRGB color){
  Serial.print(colorName);
  Serial.print(":");
  Serial.print (color.red);
  Serial.print(",");
  Serial.print (color.green);
  Serial.print(",");
  Serial.print (color.blue);
  Serial.println();  
}

/*
 * printDebugOptions() - this function outputs a debug option list with
 *                       with current status, and provides some input 
 *                       instructions
 *  
 */
void printDebugOptions() {
  Serial.println("\nDebug Options Status");
  Serial.println("Use serial input keys 1 through 9 to change debug options");
  Serial.println("Use serial input keys 0 to turn off all debug options at once");
  Serial.println("Use serial input keys QWER to emulate buttons 0 through 3");
  
  for (int o=1; o<10; o++) {    //we don't use zero
    {
      if (debugOptionsText[o]) //don't print undefined options
        Serial.printf("   Option %d = %s %s\n", o, debugOptions[o]?"ON: ":"OFF:", debugOptionsText[o]);
    }
  }
  Serial.println("\n");       //a little extra padding in the output
}

//usb keyboard button press
void OnPress(uint8_t key)
{
  Serial.print("Key Pressed:  "); Serial.println(key, HEX);
}

//usb keyboard button release
void OnRelease(uint8_t key)
{
  if (key==0x1E) modePowerUp();
  else if (key==0x1F && mode==MODE_IDLE) modeAttack();
  else if (key==0x1F && (mode==MODE_OFF || mode == MODE_LOWRIDER)) modeLowRider();
  
  else if (key==0x20 && mode==MODE_IDLE) modeDamaged();
  else if (key==0x20 && (mode==MODE_OFF || mode == MODE_DRWHO)) modeDrWho();
  
  else if (key==0x21 && mode==MODE_IDLE) modeDestroyed();
  else if (key==0x21 && (mode==MODE_OFF || mode == MODE_VADER)) modeVader();
  
  else if (key==0x22) modeTheChain();
  else if (key==0x6) volumeUp();
  else if (key==0x7) volumeDown();
  else if (key==0xE9) volumeUp();
  else if (key==0xEA) volumeDown();
  else if (key==0xCD) toggleMute();
  

  
  if (debugOptions[DEBUG_INPUT]) {
    Serial.print("Key Released: "); 
    Serial.println(key, HEX);
  }
  
}

void modePowerUp() {
  if (mode > 0 && mode < 5) return;
  mode=MODE_POWER_UP;
  clearActions();
  musicLoop=true;
  //firstLoop=true;
  queueWAV(CHANNEL_SFX1, "ACGBOOT.WAV");
  queueWAV(CHANNEL_MUSIC, "ACGBATL1.WAV");
  musicLoopFilename = "ACGBATL2.WAV";

  queueAction(ACTION_FADE_IN_NECK, 50);
  queueAction(ACTION_FADE_IN_BODY, 2000);
  queueAction(ACTION_FADE_IN_EYE,  3000);
  
 
   /*
  eyeAniMode = 1;
  neckAniMode = 1;    //todo queue these to come up over time?
  bodyAniMode = 1;
  */
}
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

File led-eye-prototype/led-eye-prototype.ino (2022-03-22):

#include <WS2812Serial.h>
#define USE_WS2812SERIAL
#include <FastLED.h>
#include <Metro.h>

#define EYE_SPEED 100
#define EYE_SPEED_TARGETING 200

Metro eyeMetro = Metro(EYE_SPEED);

//WARNING - ADJUSTING THIS SETTING COULD LEAD TO 
//EXCESS CURRENT DRAW AND POSSIBLE SYSTEM DAMAGE
#define DEFAULT_BRIGHTNESS 24 //WARNING!!!!!!!!!
//DON'T DO IT!!!!!!!!!!!!!!!!!!!!!!!!!!!!!!!!!!!



#define EYE_PATTERN_LEN 12
#define NUM_RINGS 8

//9 rings
//uint8_t eyeRingLEDSize[NUM_RINGS] = {60, 48, 40, 32, 24, 16, 12, 8, 1};

//8 rings
uint8_t eyeRingLEDSize[NUM_RINGS] = {48, 40, 32, 24, 16, 12, 8, 1};

boolean eyeRingStatus[EYE_PATTERN_LEN] = {1, 1, 1, 0, 0, 0, 1, 1, 1, 0, 0, 0};

#define EYE_TARGET_ANI_FRAMES 16
boolean eyeTargetAniFrames[EYE_TARGET_ANI_FRAMES][8] = {
                                                    {1,0,0,0,0,0,0,0},
                                                    {0,1,0,0,0,0,0,0},
                                                    {0,0,1,0,0,0,0,0},
                                                    {0,0,0,1,0,0,0,0},
                                                    {0,0,0,0,1,0,0,0},
                                                    {0,0,0,0,0,1,0,0},
                                                    {0,0,0,0,0,0,1,1},
                                                    {0,0,0,0,0,0,1,1},
                                                    {0,0,0,0,0,0,0,0},
                                                    {1,1,1,1,1,1,1,1},
                                                    {1,1,1,1,1,1,1,1},
                                                    {0,0,0,0,0,0,0,0},
                                                    {0,0,0,0,0,0,0,0},
                                                    {0,0,0,0,0,0,0,0},
                                                    {0,0,0,0,0,0,0,0},
                                                    {0,0,0,0,0,0,0,0},
                                                    };


int eyeAniMode = 0;
int eyeTargetAniFrame = 0;

#define EYE_NUM_LEDS 245
CRGB eyeLEDs[EYE_NUM_LEDS];
#define EYE_DATA_PIN 17 //left connector


void setup() {
  // put your setup code here, to run once:
  Serial.begin(115200);
  
  LEDS.addLeds<WS2812SERIAL,  EYE_DATA_PIN,   BRG>(eyeLEDs,   EYE_NUM_LEDS);
   LEDS.setBrightness(DEFAULT_BRIGHTNESS);
}

void loop() {

 if (eyeMetro.check() == 1) { // check if the metopRingOffset has passed its interval 
  
    /*for (int i = 0; i<EYE_PATTERN_LEN; i++) {
      Serial.print(eyeRingStatus[i]);
      Serial.print(" ");
    }
    Serial.println("");
   */
   
   if (eyeAniMode == 0) updateEyeRingStatus();
   else if (eyeAniMode == 1) updateEyeTargeting();
    
   FastLED.show();
   debugOptionsCheck(); 
   
 }  

  
}

void updateEyeTargeting() {

  eyeMetro.interval(EYE_SPEED_TARGETING);
  
  uint8_t lastLED = -1;
  
  for (int r=0; r<NUM_RINGS; r++) {
    Serial.print(r);

    uint8_t firstLED = 0;
    
    firstLED = lastLED + 1;
    lastLED =  lastLED + eyeRingLEDSize[r];

    for (int l=firstLED; l<=lastLED; l++){
      if (eyeTargetAniFrames[eyeTargetAniFrame][r]) 
         eyeLEDs[l] = CRGB::Red;
      else eyeLEDs[l] = CRGB::Black; 
    }

    Serial.print("EyeRing: ");
    Serial.print(r);
    Serial.print(": ");
    Serial.print(firstLED);
    Serial.print(": ");
    Serial.println(lastLED); 
    
    if (eyeTargetAniFrame == EYE_TARGET_ANI_FRAMES) {
      fadeToBlackBy(eyeLEDs, EYE_NUM_LEDS, 80);
      eyeAniMode = 0;
      eyeTargetAniFrame = 0;
      eyeMetro.interval(EYE_SPEED);
    } //end if
  } //end for

  if (eyeAniMode == 1) eyeTargetAniFrame++;
}

void updateEyeRingStatus() {

  eyeMetro.interval(EYE_SPEED);
  //increment the status array
  boolean eyeRingStatusTemp[EYE_PATTERN_LEN];
     
  for (int i = 0; i<EYE_PATTERN_LEN; i++) {
    eyeRingStatusTemp[i] = eyeRingStatus[i];
  }
  
 /* left to right
  for (int i = 0; i<EYE_PATTERN_LEN; i++) {
    if (i==0) {
      eyeRingStatus[i] = eyeRingStatusTemp[EYE_PATTERN_LEN-1];
    }
    else eyeRingStatus[i] = eyeRingStatusTemp[i-1];
  }
  */
  //right to left
  
  for (int i = 0; i<EYE_PATTERN_LEN; i++) {
    if (i==EYE_PATTERN_LEN-1) {
      eyeRingStatus[i] = eyeRingStatusTemp[0];
    }
    else eyeRingStatus[i] = eyeRingStatusTemp[i+1];
  }
  
  
  //update the rings

  uint8_t lastLED = -1;
  
  for (int r = 0; r<NUM_RINGS; r++){
    uint8_t firstLED = 0;
    
    firstLED = lastLED + 1;
    lastLED =  lastLED + eyeRingLEDSize[r];

    for (int l=firstLED; l<=lastLED; l++){
      if (eyeRingStatus[r]) 
         //dim the first and last ring 
         if (r ==0 || r == NUM_RINGS-1) eyeLEDs[l].setHSV(160,255,128); 
         else eyeLEDs[l].setHSV(160,255,255); 
        //eyeLEDs[l] = CRGB::Blue;
      else eyeLEDs[l] = CRGB::Black;
    }

    
    Serial.print("EyeRing: ");
    Serial.print(r);
    Serial.print(": ");
    Serial.print(firstLED);
    Serial.print(": ");
    Serial.println(lastLED);  
     
  }
  
    
}

/*
 * debugOptionsCheck() - this function checks the Serial input and
 *                       changes debug options as well as emulates some 
 *                       button presses
 *                       
 */
void debugOptionsCheck() {
  int incomingByte = 0;
  
  if (Serial.available() > 0) {
      // read the incoming byte:
      incomingByte = Serial.read();
      //int option;
      
      switch (incomingByte) {
          /*
          case '0':                         //turn all options off
            for (int o = 1; o<10; o++) {    //we dont use zero
              debugOptions[o] = 0;
            }
            Serial.println ("All debug options turned OFF");
            break;
            
          case '1' ... '9': 
            option = incomingByte - '0';
            debugOptions[option] = !debugOptions[option]; 
            //Serial.printf("Debug option %d is now %s\n", option, debugOptions[option]?"ON":"OFF");
            break;

          case 'q': mapAction(SOURCE_BUTTON, 0, 0); break;
          case 'w': mapAction(SOURCE_BUTTON, 1, 0); break;
          case 'e': mapAction(SOURCE_BUTTON, 2, 0); break;
          */
          case 't': eyeAniMode = 1; Serial.println("Targeting!"); break;
          }
         
         //rprintDebugOptions();
          
      }
       
}

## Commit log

2022-03-20 upload LED prototypes
2022-03-27 body pattern generation switch to CRGB
2022-04-16 initial upload of 3d printing files
    [Parametric LED Ring Holder v2.scad, Parametric LED Ring Holder v2_1.scad, Parametric LED Ring Holder v2_2.scad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]
2022-04-16 major update
    Neck LEDs now 6 rows and functional!
2022-05-25 update BOM
2022-05-25 added connectors
